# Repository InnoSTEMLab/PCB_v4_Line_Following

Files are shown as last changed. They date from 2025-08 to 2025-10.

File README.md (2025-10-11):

# PCB_v5_Line_Following

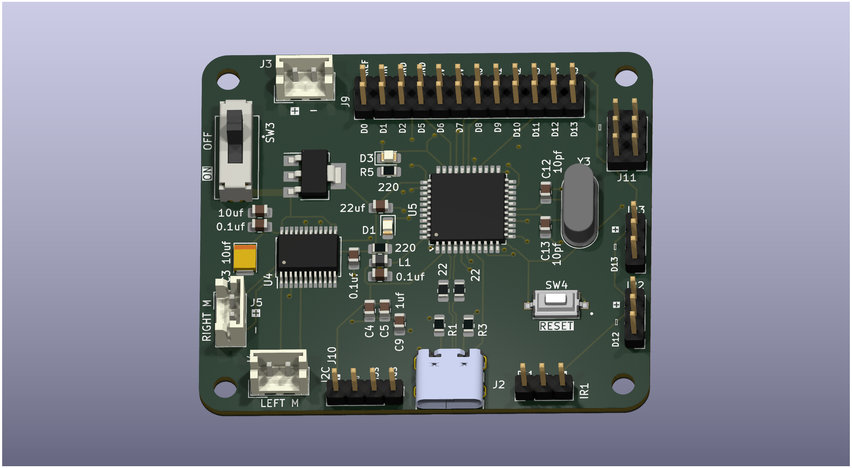
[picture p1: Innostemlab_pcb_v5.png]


## Updates:
- New IC Atemga328pa -> Atemga32u4. Takes D+ and D- from usb no need for usb to uart controller
- Motor connectors moved in one section of the board
- Trace fixed for switch that was keeping motor controller on all the time. Motors will be off when usb c connected only.
- Power conversion only happens in one part of the pcb
- USB C footprint updated to current part we have previosuily ordered. No more issues soldering them.
- Decoupling capacitors added to motor driver and termination resistors to USB C data lines

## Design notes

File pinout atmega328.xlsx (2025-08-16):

P | D | in/out | for | DESCP
PD0 | D0
PD1 | D1
PD2 | D2 | OUT | AINT1 | CONTROL A MOTOR DIRECTION
PD3 | D3 | OUT | PWMA | SPEED A
PD4 | D4 | OUT | AINT2 | CONTROL A MOTOR DIRECTION
PD5 | D5 | OUT | PWMB | SPEED B
PD6 | D6 | OUT | BINT1 | CONTROL B MOTOR DIRECTION
PD7 | D7 | OUT | BINT2 | CONTROL B MOTOR DIRECTION
PC0 | A0
PC1 | A1
PC2 | A2
PC3 | A3
PC4 | A4 |  |  | SDA
PC5 | A5 |  |  | SCL
PC6 | Nan
PB0 | D8 | OUT
PB1 | D9
PB2 | D10
PB3 | D11 |  |  | IR1
PB4 | D12 |  |  | IR2
PB5 | D13 |  |  | IR3
PB6 | Nan
PB7 | Nan

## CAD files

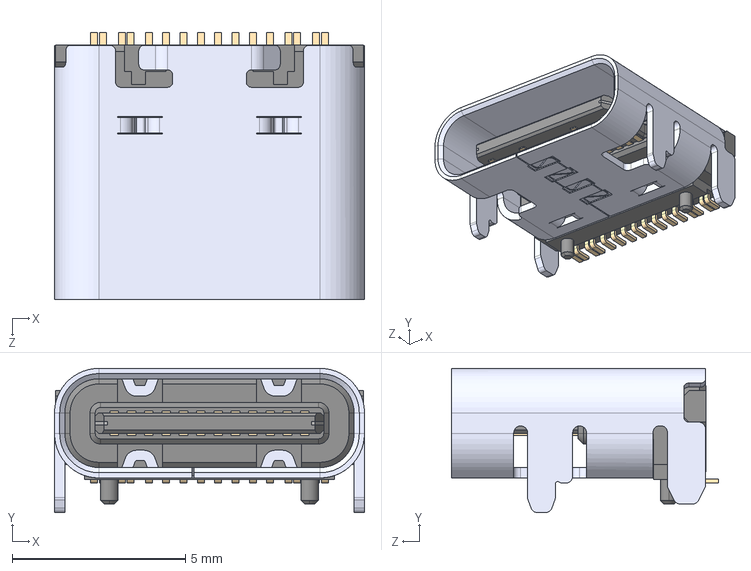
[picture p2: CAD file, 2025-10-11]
models/USB4105-GF-A-060.step
8.94 x 4.16 x 7.71 mm

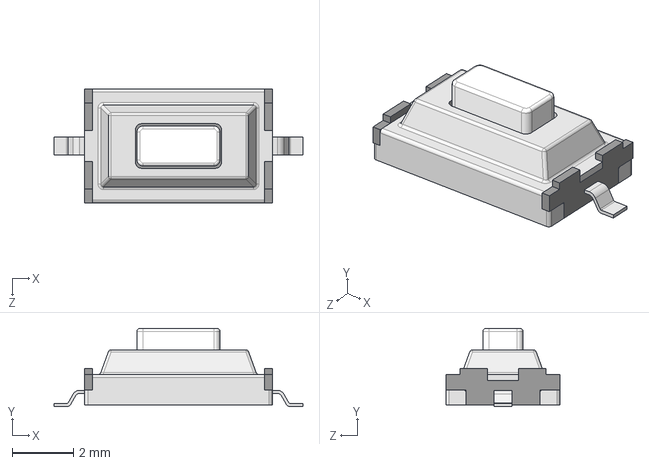
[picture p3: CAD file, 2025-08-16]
models/TS09-63-25-WT-260-SMT-TR.STEP
8.10 x 2.55 x 3.70 mm

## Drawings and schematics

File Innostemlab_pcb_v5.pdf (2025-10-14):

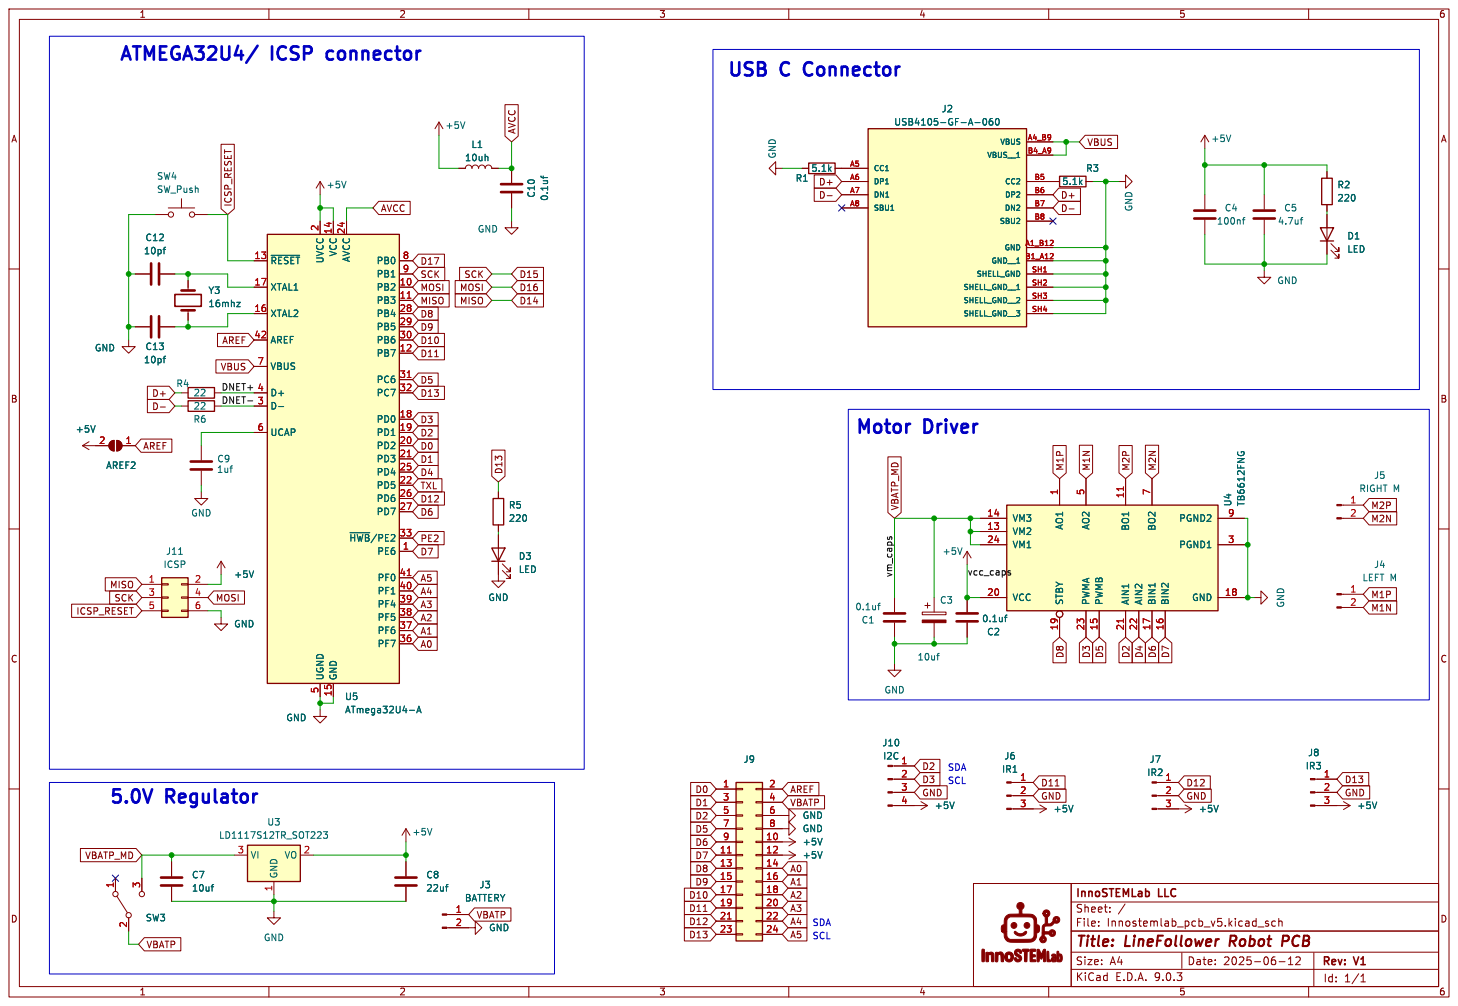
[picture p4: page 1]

5 VCC 14 GND 15 AVCC 24 PB0 8 PB1 9 PB2 10 PB3 11 PB4 28 PB5 29 PB6 30 PB7 12 PC6 31 PC7 32 PD0 18 PD1 19 PD2 20 PD3 21 PD4 25 PD5 22 PD6 26 PD7 27 ~{HWB}/PE233 PE6 1 PF0 41 PF1 40 PF4 39 PF5 38 PF6 37 PF7 36 U5ATmega32U4-A D13 D2 D0 D1 D- D+ M1N M1N D5 D2 D4 D7

5 VCC 14 GND 15 AVCC 24 PB0 8 PB1 9 PB2 10 PB3 11 PB4 28 PB5 29 PB6 30 PB7 12 PC6 31 PC7 32 PD0 18 PD1 19 PD2 20 PD3 21 PD4 25 PD5 22 PD6 26 PD7 27 ~{HWB}/PE233 PE6 1 PF0 41 PF1 40 PF4 39 PF5 38 PF6 37 PF7 36 GND

File: Innostemlab_pcb_v5.kicad_sch Sheet: /
Id: 1/1 Title: LineFollower Robot PCB

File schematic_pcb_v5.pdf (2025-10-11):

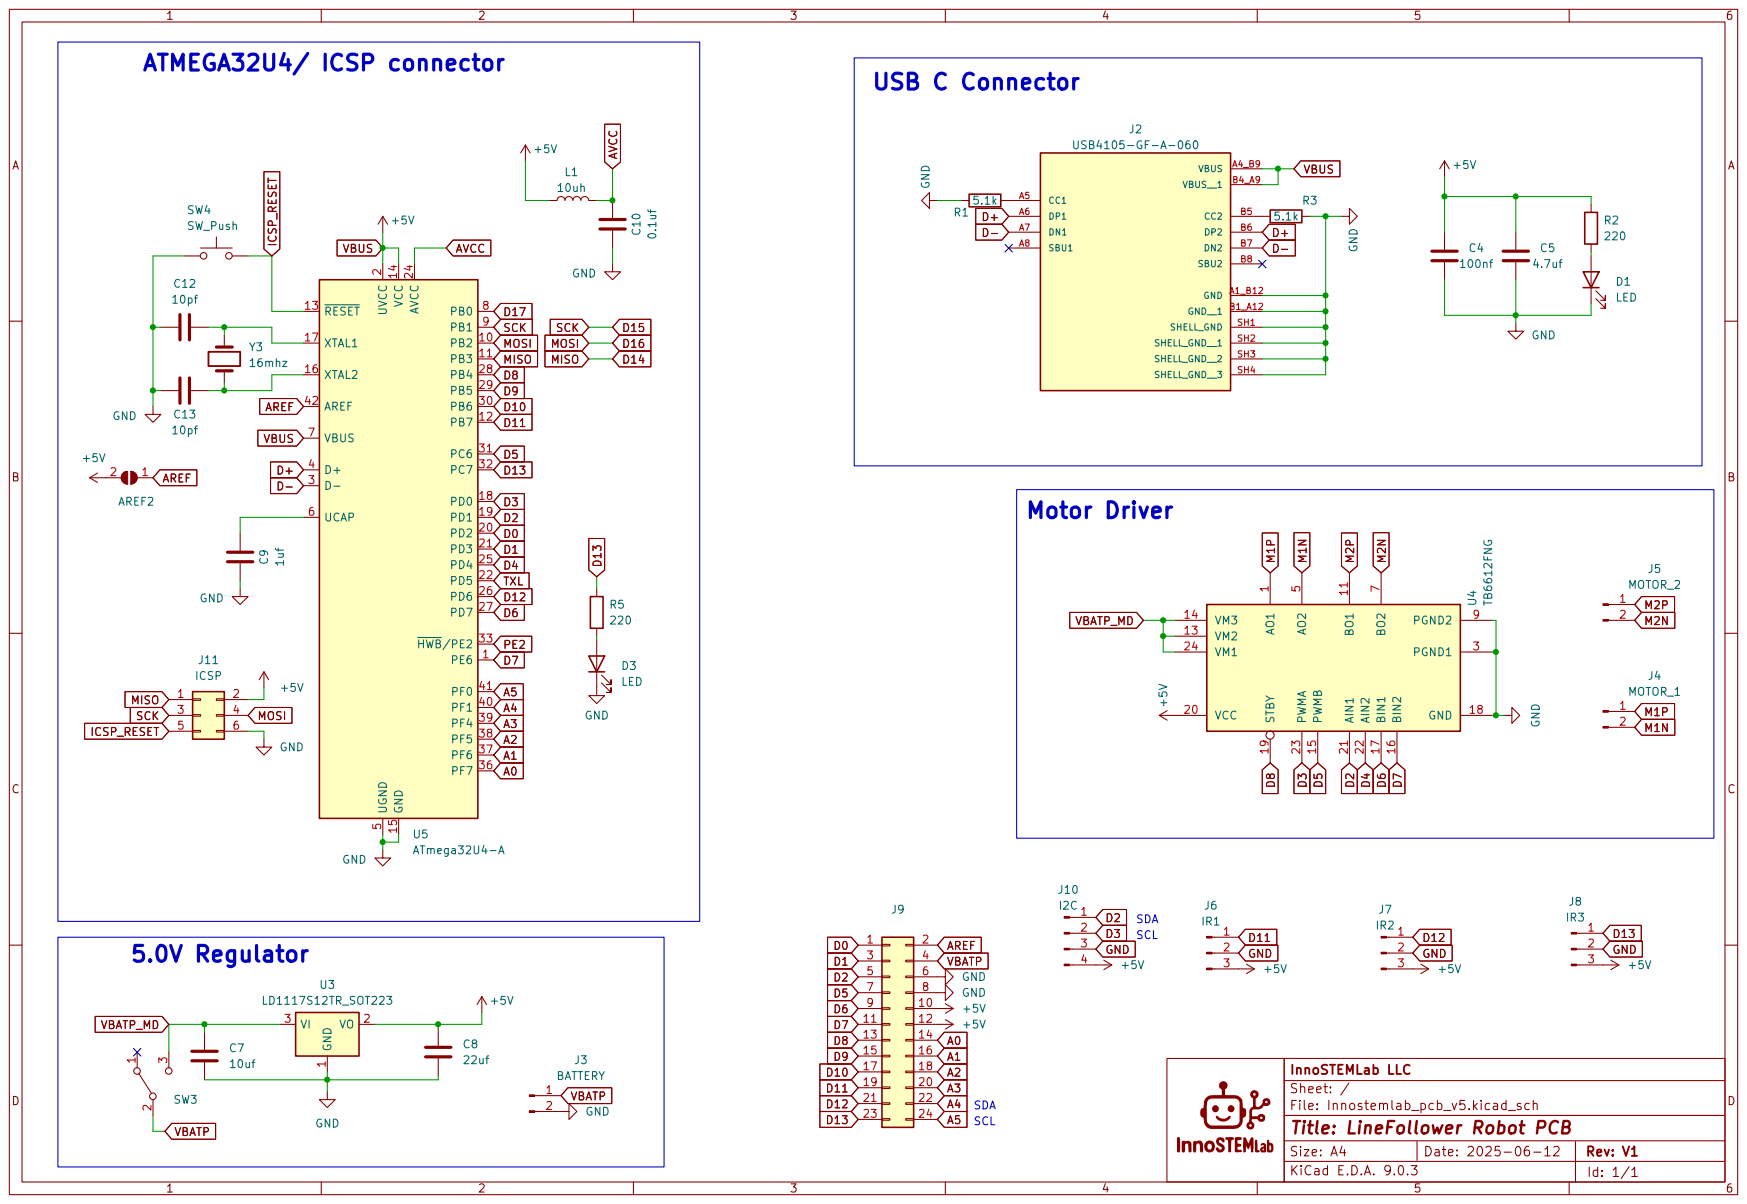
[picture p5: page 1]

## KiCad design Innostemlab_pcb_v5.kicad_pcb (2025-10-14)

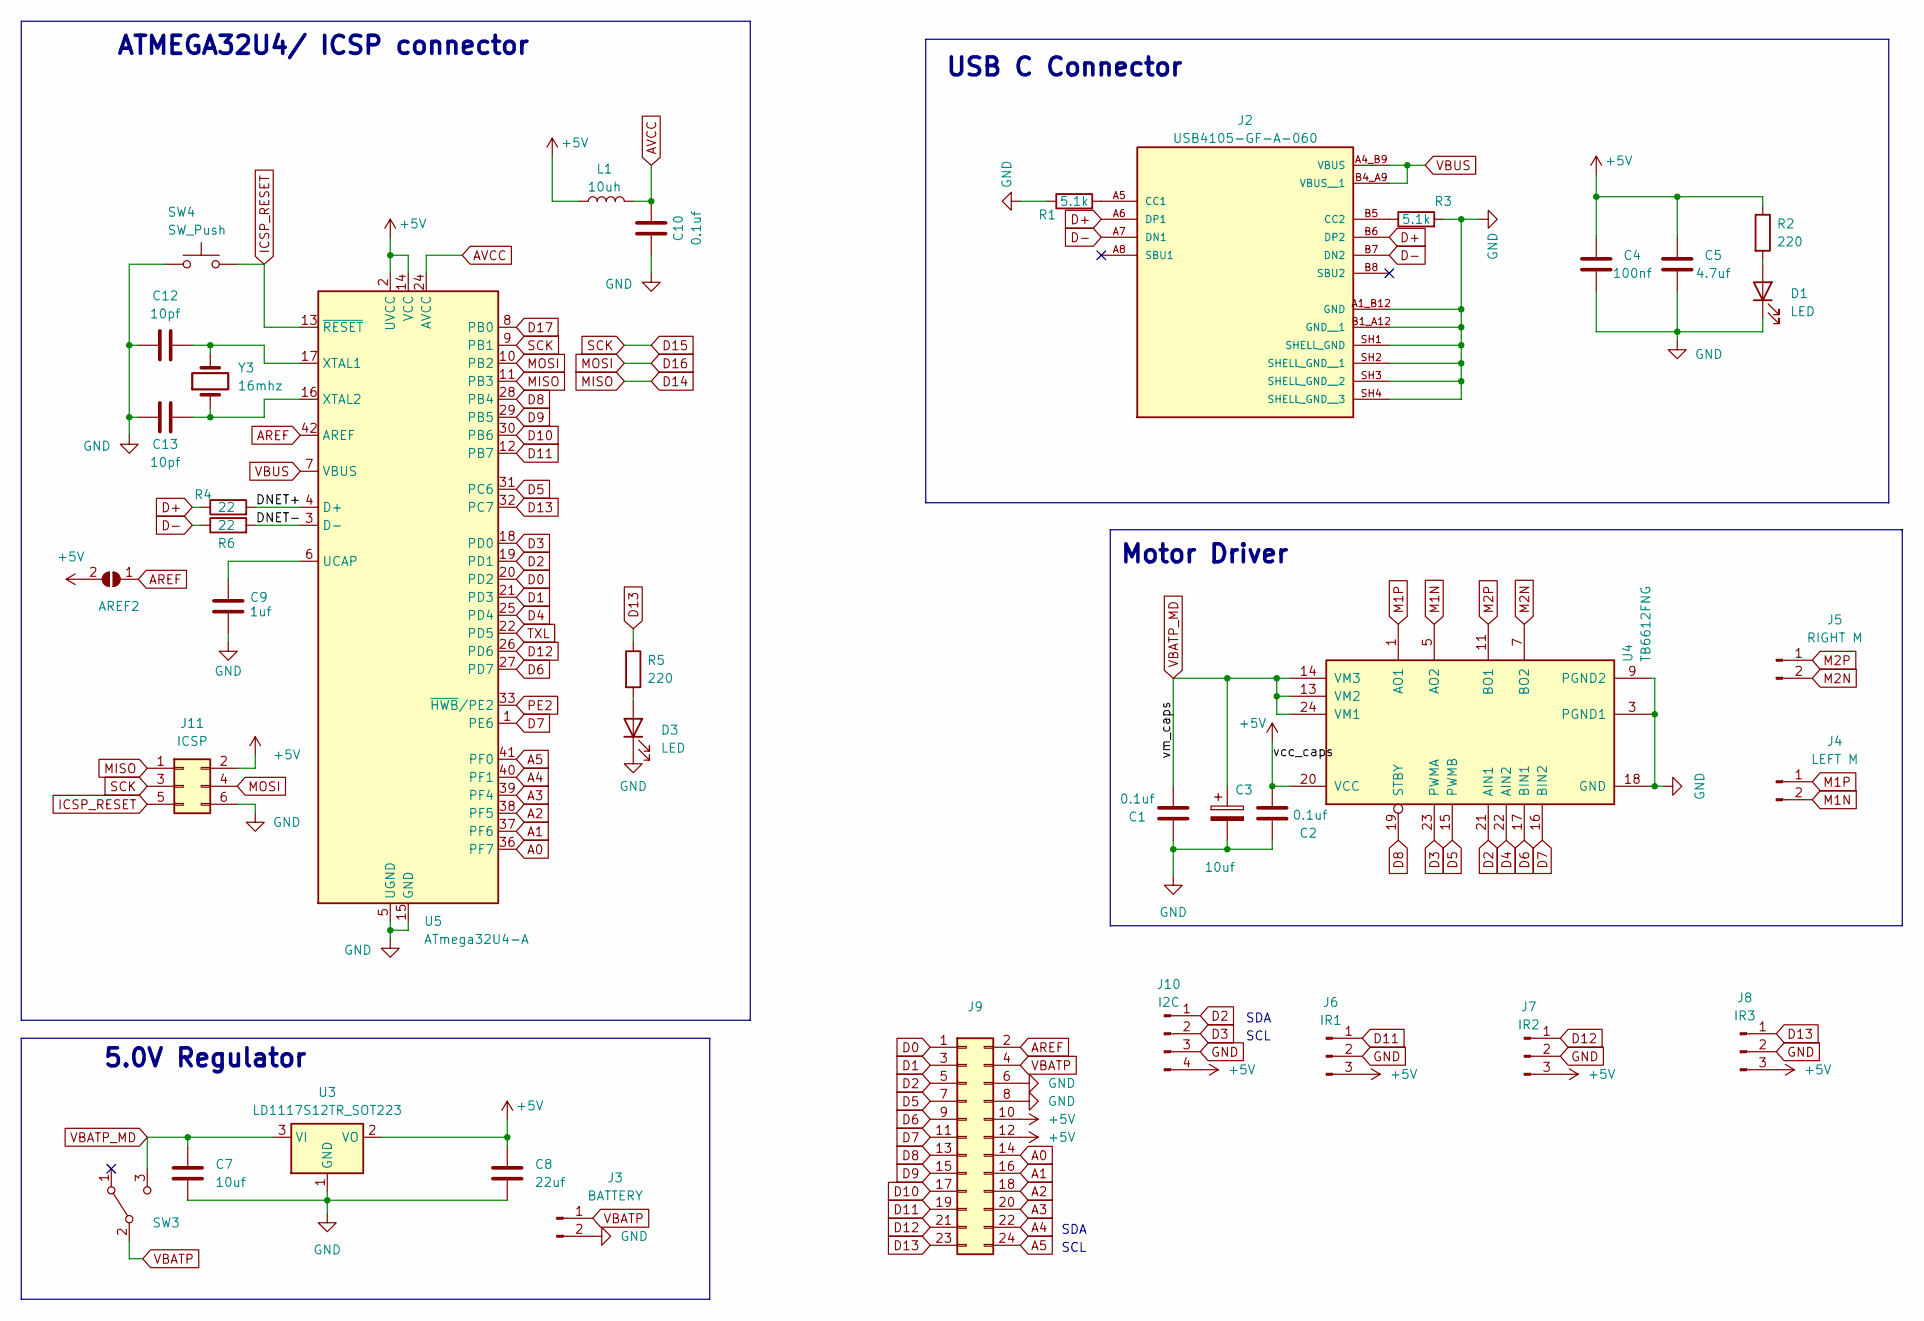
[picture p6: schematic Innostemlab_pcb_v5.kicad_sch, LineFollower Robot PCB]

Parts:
AREF2: SolderJumper_2_Open; SolderJumper-2_P1.3mm_Open_RoundedPad1.0x1.5mm
C1, C2, C10: 0.1uf; C_0805_2012Metric_Pad1.18x1.45mm_HandSolder
C3: 10uf; CP_EIA-3528-12_Kemet-T
C4: 100nf; C_0805_2012Metric_Pad1.18x1.45mm_HandSolder
C5: 4.7uf; C_0805_2012Metric_Pad1.18x1.45mm_HandSolder
C7: 10uf; C_0805_2012Metric_Pad1.18x1.45mm_HandSolder
C8: 22uf; C_0805_2012Metric_Pad1.18x1.45mm_HandSolder
C9: 1uf; C_0805_2012Metric_Pad1.18x1.45mm_HandSolder
C12, C13: 10pf; C_0805_2012Metric_Pad1.18x1.45mm_HandSolder
D1, D3: LED; LED_0805_2012Metric_Pad1.15x1.40mm_HandSolder
J2: USB4105-GF-A-060; GCT_USB4105-GF-A-060; PARTREV B3
J3: BATTERY; JST_EH_B2B-EH-A_1x02_P2.50mm_Vertical
J4: LEFT M; JST_EH_B2B-EH-A_1x02_P2.50mm_Vertical
J5: RIGHT M; JST_EH_B2B-EH-A_1x02_P2.50mm_Vertical
J6: IR1; PinHeader_1x03_P2.54mm_Vertical
J7: IR2; PinHeader_1x03_P2.54mm_Vertical
J8: IR3; PinHeader_1x03_P2.54mm_Vertical
J9: Conn_02x12_Odd_Even; PinHeader_2x12_P2.54mm_Vertical
J10: I2C; PinHeader_1x04_P2.54mm_Vertical
J11: ICSP; PinHeader_2x03_P2.54mm_Vertical
L1: 10uh; L_0805_2012Metric
R1, R3: 5.1k; R_0805_2012Metric_Pad1.20x1.40mm_HandSolder
R2, R5: 220; R_0805_2012Metric_Pad1.20x1.40mm_HandSolder
R4, R6: 22; R_0805_2012Metric_Pad1.20x1.40mm_HandSolder
SW3: SW_SPDT; SW_SLW-121586-5A-D
SW4: SW_Push; SW_TS09-63-25-WT-260-SMT-TR
U3: LD1117S12TR_SOT223; SOT-223-3_TabPin2
U4: TB6612FNG; SSOP-24_5.3x8.2mm_P0.65mm
U5: ATmega32U4-A; TQFP-44_10x10mm_P0.8mm
Y3: 16mhz; Crystal_HC49-4H_Vertical

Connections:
+5V: AREF2.2 (B), C2.2, C4.2, C5.2, C8.1, J6.3, J7.3, J8.3, J9.10, J9.12, J10.4, J11.2, L1.1, R2.1, U3.2 (VO), U4.20 (VCC), U5.2 (UVCC), U5.14 (VCC), U5.34 (VCC)
/DNET+: R4.2, U5.4 (D+)
/DNET-: R6.2, U5.3 (D-)
A0: J9.14, U5.36 (PF7)
A1: J9.16, U5.37 (PF6)
A2: J9.18, U5.38 (PF5)
A3: J9.20, U5.39 (PF4)
A4: J9.22, U5.40 (PF1)
A5: J9.24, U5.41 (PF0)
AREF: AREF2.1 (A), J9.2, U5.42 (AREF)
AVCC: C10.2, L1.2, U5.24 (AVCC), U5.44 (AVCC)
D0: J9.1, U5.20 (PD2)
D1: J9.3, U5.21 (PD3)
D2: J9.5, J10.1, U4.21 (AIN1), U5.19 (PD1)
D3: J10.2, U4.23 (PWMA), U5.18 (PD0)
D4: U4.22 (AIN2), U5.25 (PD4)
D5: J9.7, U4.15 (PWMB), U5.31 (PC6)
D6: J9.9, U4.17 (BIN1), U5.27 (PD7)
D7: J9.11, U4.16 (BIN2), U5.1 (PE6)
D8: J9.13, U4.19 (STBY), U5.28 (PB4)
D9: J9.15, U5.29 (PB5)
D10: J9.17, U5.30 (PB6)
D11: J6.1, J9.19, U5.12 (PB7)
D12: J7.1, J9.21, U5.26 (PD6)
D13: J8.1, J9.23, R5.1, U5.32 (PC7)
D14: J11.1, U5.11 (PB3)
D15: J11.3, U5.9 (PB1)
D16: J11.4, U5.10 (PB2)
D17: U5.8 (PB0)
D+: J2.A6 (DP1), J2.B6 (DP2), R4.1
D-: J2.A7 (DN1), J2.B7 (DN2), R6.1
GND: C1.1, C2.1, C3.2, C4.1, C5.1, C7.2, C8.2, C9.1, C10.1, C12.1, C13.1, D1.1 (K), D3.1 (K), J2.A1_B12 (GND), J2.B1_A12 (GND__1), J2.SH1 (SHELL_GND), J2.SH2 (SHELL_GND__1), J2.SH3 (SHELL_GND__2), J2.SH4 (SHELL_GND__3), J3.2, J6.2, J7.2, J8.2, J9.6, J9.8, J10.3, J11.6, R1.1, R3.2, SW4.1, U3.1 (GND), U4.3 (PGND1), U4.4 (PGND1), U4.9 (PGND2), U4.10 (PGND2), U4.18 (GND), U5.5 (UGND), U5.15 (GND), U5.23 (GND), U5.35 (GND), U5.43 (GND)
ICSP_RESET: J11.5, SW4.2, U5.13 (~RESET)
M1N: J4.2, U4.5 (AO2), U4.6 (AO2)
M1P: J4.1, U4.1 (AO1), U4.2 (AO1)
M2N: J5.2, U4.7 (BO2), U4.8 (BO2)
M2P: J5.1, U4.11 (BO1), U4.12 (BO1)
unnamed: D1.2 (A), R2.2
unnamed: D3.2 (A), R5.2
unnamed: J2.A5 (CC1), R1.2
unnamed: J2.B5 (CC2), R3.1
unnamed: C9.2, U5.6 (UCAP)
unnamed: C12.2, U5.17 (XTAL1), Y3.2
unnamed: C13.2, U5.16 (XTAL2), Y3.1
PE2: U5.33 (~HWB/PE2)
TXL: U5.22 (PD5)
VBATP: J3.1, J9.4, SW3.2 (B)
VBATP_MD: C1.2, C3.1, C7.1, SW3.3 (C), U3.3 (VI), U4.13 (VM2), U4.14 (VM3), U4.24 (VM1)
VBUS: J2.A4_B9 (VBUS), J2.B4_A9 (VBUS__1), U5.7 (VBUS)

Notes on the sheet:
USB C Connector
SCL
SDA
ATMEGA32U4/ ICSP connector
5.0V Regulator
Motor Driver

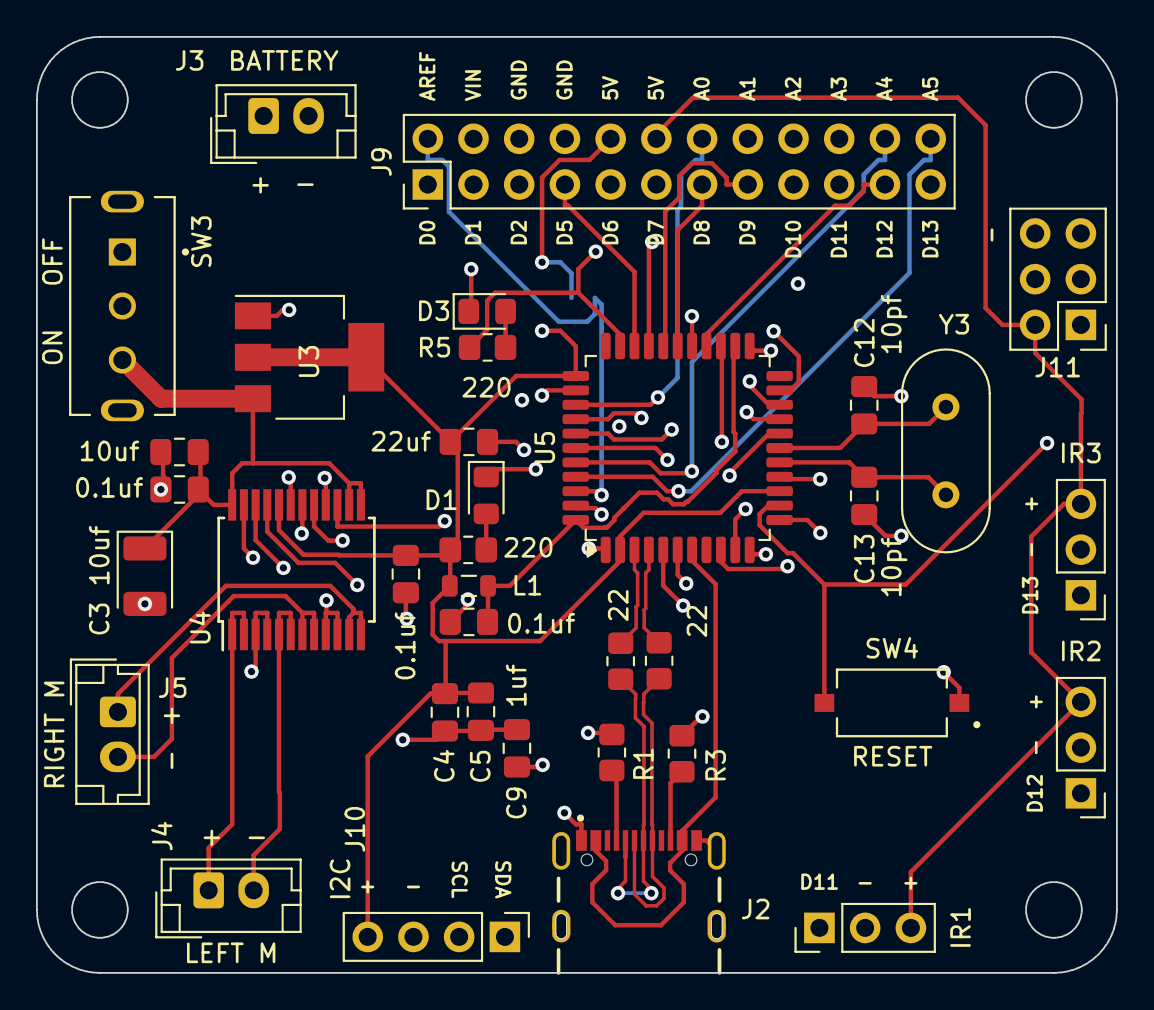
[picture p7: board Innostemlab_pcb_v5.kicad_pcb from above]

Board: 4 copper layers, 60.0 x 52.0 mm, 37 parts (1 on the bottom side), 46 nets.

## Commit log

2025-09-25 New changes with atmega32u4 no programmer, and putting all motors in one section
    [Innostemlab_pcb_v4.kicad_pcb, Innostemlab_pcb_v4.kicad_sch, Innostemlab_pcb_v5.kicad_pcb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]
2025-09-25 docs: created a schematic pdf
2025-10-08 Added caps in TB motor driver, added 22 ohm resistors in usb c data lines, changed part number for AVCC low pass filter, LD1117 datasheet from digikey shows same implementation
    [Innostemlab_pcb_v5.kicad_pcb, Innostemlab_pcb_v5.kicad_sch]
2025-10-08 changed label to left and right for motor, the other edits happened in previous commmit
    [Innostemlab_pcb_v5.kicad_pcb]
2025-10-14 Added electrolytic cap, changed motor nammmes to left and right
    [Innostemlab_pcb_v5.kicad_pcb, Innostemlab_pcb_v5.kicad_sch]
2025-10-14 updated vbus and 5v to be seperate so that usb only powers atmega chip. battery required for other sensors and components
    [Innostemlab_pcb_v5.kicad_pcb, Innostemlab_pcb_v5.kicad_sch]
